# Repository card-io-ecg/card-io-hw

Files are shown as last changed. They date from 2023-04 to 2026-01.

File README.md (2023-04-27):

Card/IO hardware
================

Card/IO is an open source, single lead ECG in a business card-like format.

The project contains two PCB designs, created using KiCAD 7:
 
 - main_board: main/carrier board, which is a 4 layer PCB containing the MCU, display, battery and related circuitry
 - frontend: the ECG frontend, ADC, and touch detection/wakeup generator, implemented as a solder-on daughter board

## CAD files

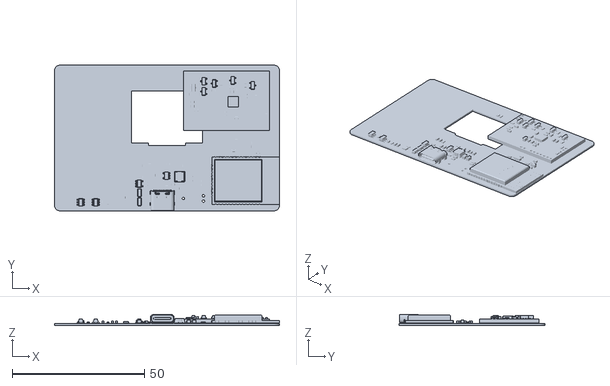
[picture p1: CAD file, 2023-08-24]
enclosure/main_board.stl
85.0 x 55.0 x 4.26

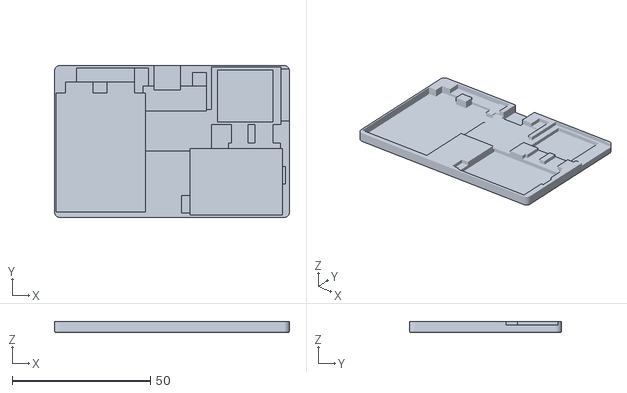
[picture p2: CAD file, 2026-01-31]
enclosure/enclosure.stl
85.0 x 55.0 x 4.00

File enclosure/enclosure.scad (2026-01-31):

include <rounded_rect.scad>

$fn = 50;

/* Set to false if you want to render the box */
design = false; // draw the box or the PCB and the part cutouts
drawBoard = false; // draw the board on top of the box in !design
fullHeight = true; // display flat overlays or the full height cutouts

flatCutout = design && !fullHeight;

boardThickness = 0.8;
nominalBoardWidth = 85;
nominalBoardHeight = 55;

partMaskHeight =       flatCutout ? 0.1 : 1.5;
highPartMaskHeight =   flatCutout ? 0.1 : 2;
frontendMaskHeight =   flatCutout ? 0.1 : 3;
espMaskHeight =        flatCutout ? 0.1 : 3;
espPcbMaskHeight =     flatCutout ? 0.1 : 1.2;
batteryMaskHeight =    flatCutout ? 0.1 : 3;
usbHeight =            flatCutout ? 1   : 3.4;

wallThickness = 0.6;
wallHeight = 3.4;
edgeRounding = 1;
cornerRadius = 1.4;

boxWidth = nominalBoardWidth;
boxHeight = nominalBoardHeight;

module boardAndParts()
{
    /* Display */
    color("blue")
    translate([29, 24.6, -partMaskHeight])
    cube([27.8, 20, partMaskHeight]);
    translate([29, 16, 0])
    cube([27.8, 15, partMaskHeight]);
    //*/

    /* USB port body */
    color("purple")
    translate([36, -0.2, 0])
    cube([9.5, 9, usbHeight]);
    //*/

    /* Battery */
    translate([4, 6, 0])
    cube([10, 7, batteryMaskHeight]);
    translate([19, 6, 0])
    cube([10, 7, batteryMaskHeight]);
    translate([0.6, 10, 0])
    cube([32.4, 43, batteryMaskHeight]);
    //*/

    /* Battery protection */
    translate([8, 1, 0])
    cube([21, 5, highPartMaskHeight]);
    //*/

    /* Battery charger */
    translate([29, 1, 0])
    cube([5, 12, partMaskHeight]);
    //*/

    /* PSU */
    color("purple")
    translate([32, 7.5, 0])
    cube([23, 9, highPartMaskHeight]);
    //*/

    /* ===== MCU ===== */
    translate([60, 1.2, 0])
    cube([27, 18.8, espPcbMaskHeight]);
    translate([59, 1.6, 0])
    cube([20, 18.8, espMaskHeight]);
    /* MCU pads */
    color("purple")
    translate([56.8, 0.6, 0])
    cube([25.2, 20.8, partMaskHeight]);
    //*/
    /* MCU others */
    // XTAL32K
    translate([64, 21, 0])
    cube([6, 7, partMaskHeight]);
    // reset resistor / bypass caps
    translate([72.5, 21, 0])
    cube([6.5, 8, partMaskHeight]);
    // I2C resistors
    color("purple")
    translate([50, 2.5, 0])
    cube([5, 5, partMaskHeight]);
    //*/

    /* ===== Analog frontend ===== */
    translate([49, 30, 0])
    cube([33.5, 24, frontendMaskHeight]);
    /* AFE pads */
    color("purple")
    translate([46, 47, 0])
    cube([3, 6.3, partMaskHeight]);
    color("purple")
    translate([80.5, 36.5, 0])
    cube([3, 6.3, partMaskHeight]);
    color("purple")
    translate([63, 28, 0])
    cube([18.7, 3, partMaskHeight]);
    //*/
}

if (!design)
{
    rotate([180, 0, 0])
    union() {
        translate([0, 0, - wallHeight - wallThickness])
        difference()
        {
            /* ===== Shell ===== */
            difference()
            {
                /* Box */
                translate([wallThickness, wallThickness, 0])
                minkowski()
                {
                    roundedRect([boxWidth-2*wallThickness, boxHeight-2*wallThickness, wallHeight], cornerRadius, false);
                    sphere(wallThickness);
                }
                    
                /* cut the bottom half */
                translate([-boxWidth, -boxHeight, -wallHeight])
                cube([3 * boxWidth, 3 * boxHeight, wallHeight]);
            }

            boardAndParts();
        }
        
        if (drawBoard) {
            color("green")
            translate([0, 0, -wallHeight -wallThickness - boardThickness])
            import("main_board.stl");
        }
    }
}
else
{
    color("green")
    translate([0, 0, -boardThickness])
    import("main_board.stl");
    boardAndParts();
}

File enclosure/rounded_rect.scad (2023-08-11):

module roundedRect(size, radius, center=false)
{
    x = size[0];
    y = size[1];
    z = size[2];
	
		dx = center ? x/2 : 0;
		dy = center ? y/2 : 0;
		dz = center ? z/2 : 0;
	
	translate([dx, dy, -dz])
    linear_extrude(height=z)
	hull()
    {
        // place 4 circles in the corners, with the given radius
        translate([radius, radius, 0])
        circle(r=radius);
		
        translate([x - radius, radius, 0])
        circle(r=radius);
		
        translate([radius, y - radius, 0])
        circle(r=radius);
		
        translate([x - radius, y - radius, 0])
        circle(r=radius);
    }
}

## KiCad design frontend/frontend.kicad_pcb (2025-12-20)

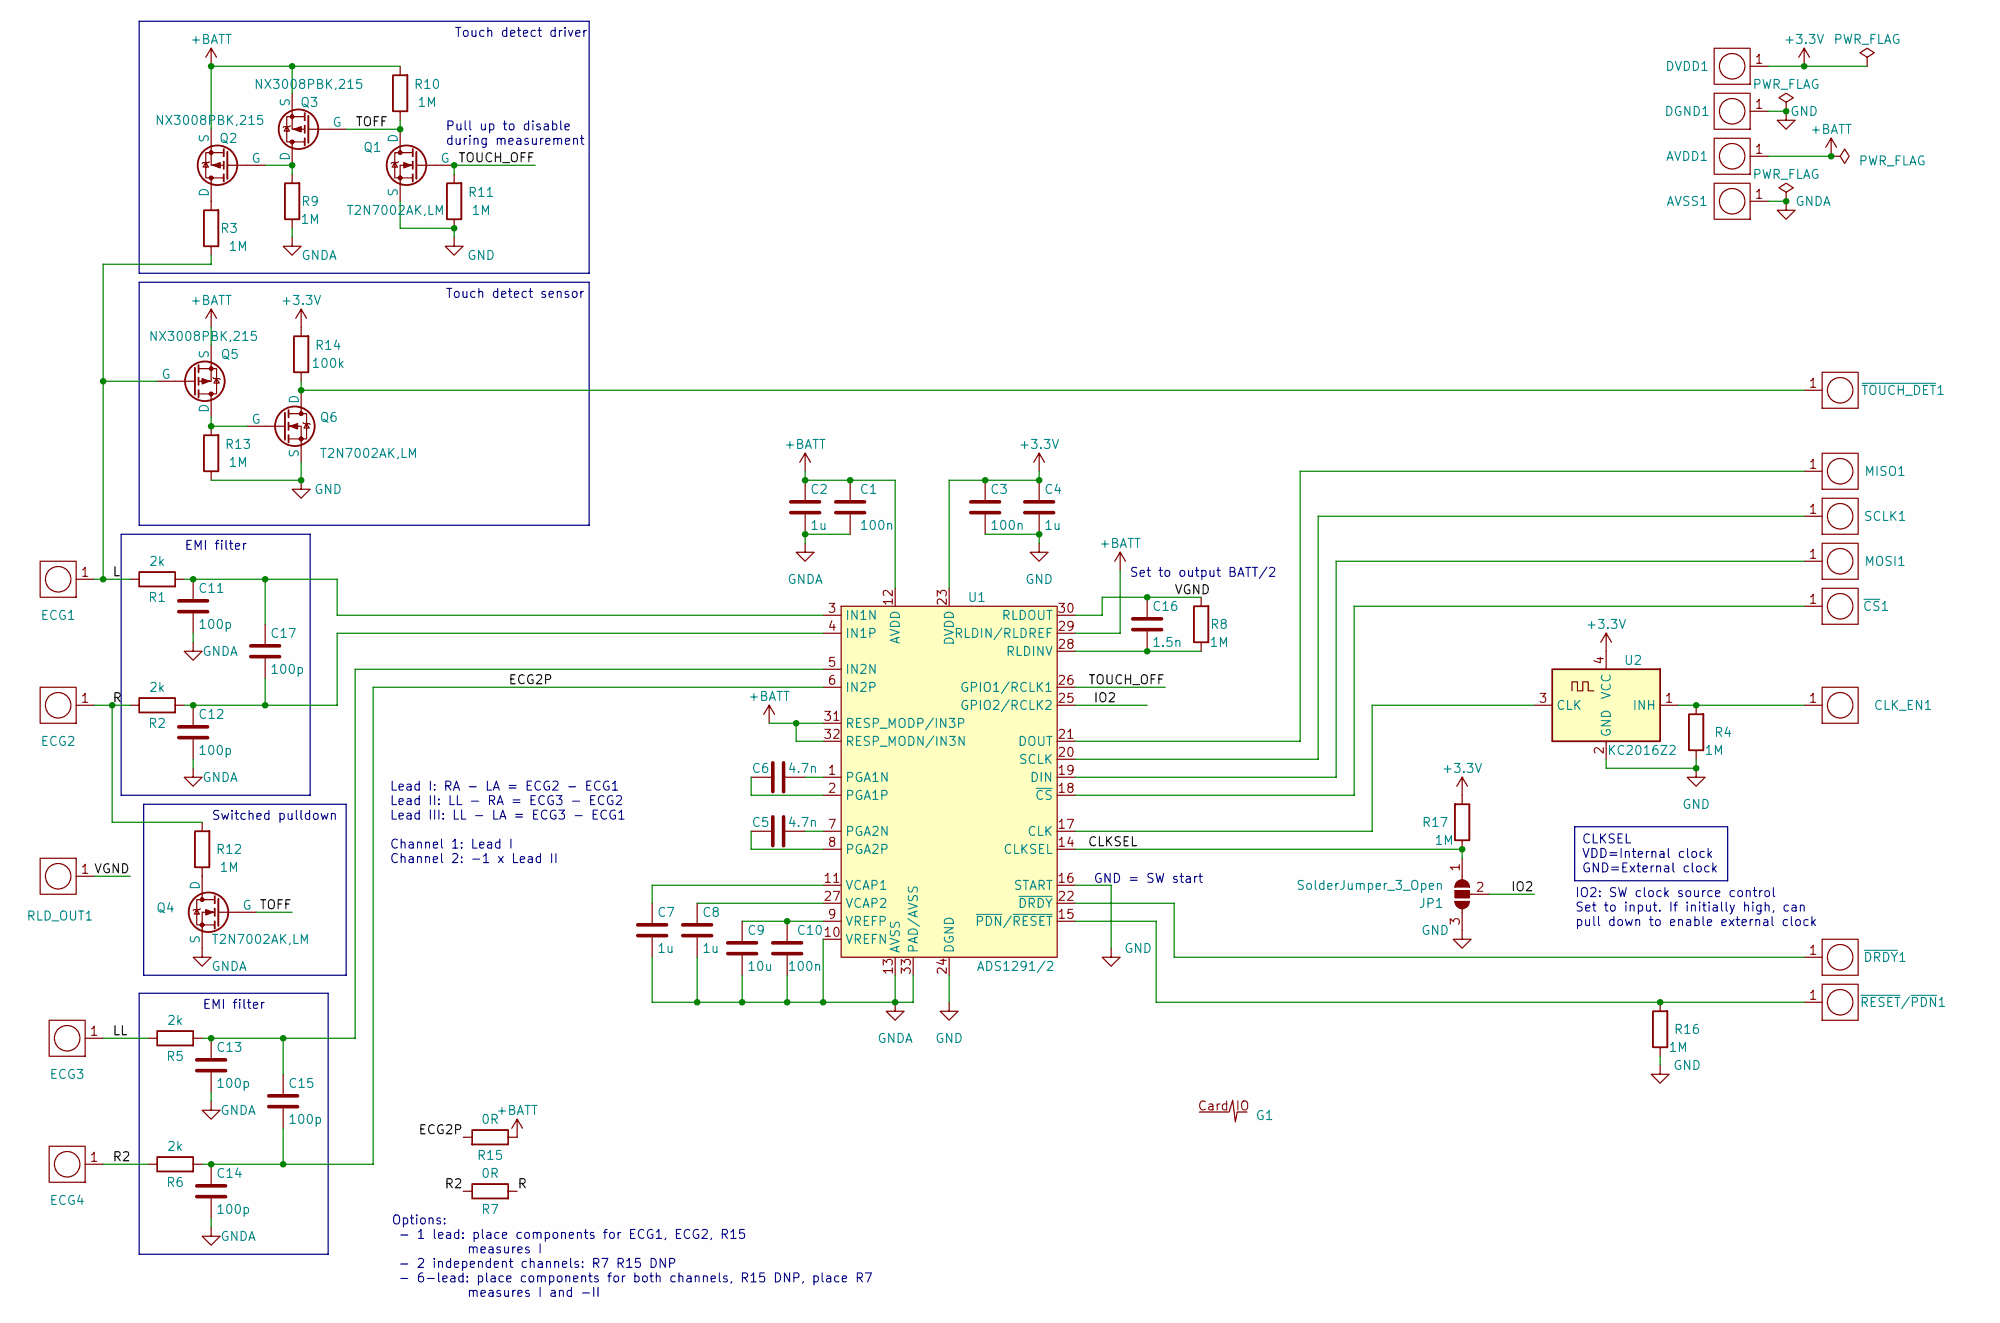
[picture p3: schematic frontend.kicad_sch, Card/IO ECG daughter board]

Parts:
AVDD1: PAD
AVSS1: PAD
C1, C3, C10: 100n; C_0603_1608Metric
C2, C4, C7, C8: 1u; C_0603_1608Metric
C5, C6: 4.7n; C_0603_1608Metric
C9: 10u; C_0805_2012Metric
C11, C12, C13, C14, C15, C17: 100p; C_0603_1608Metric
C16: 1.5n; C_0603_1608Metric
CLK_EN1: PAD
DGND1: PAD
DVDD1: PAD
ECG1, ECG2, ECG3, ECG4: PAD
G1: logo
JP1: SolderJumper_3_Open; SolderJumper-3_P1.3mm_Open_RoundedPad1.0x1.5mm
MISO1: PAD
MOSI1: PAD
Q1, Q4, Q6: T2N7002AK,LM; SOT-23
Q2, Q3, Q5: NX3008PBK,215; SOT-23
R1, R2, R5, R6: 2k; R_0603_1608Metric
R3, R4, R8, R9, R10, R11, R12, R13, R16, R17: 1M; R_0603_1608Metric
R7, R15: 0R; R_0603_1608Metric
R14: 100k; R_0603_1608Metric
RLD_OUT1: PAD
SCLK1: PAD
U1: ADS1291/2; ADS1291-2
U2: KC2016Z2; KC2016Z
~{CS}1: PAD
~{DRDY}1: PAD
~{RESET}/~{PDN}1: PAD
~{TOUCH_DET}1: PAD

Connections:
+3.3V: C3.1, C4.1, DVDD1.1, R14.2, R17.2, U1.23 (DVDD), U2.4 (VCC)
+BATT: AVDD1.1, C1.1, C2.1, Q2.2 (S), Q3.2 (S), Q5.2 (S), R10.2, R15.1, U1.12 (AVDD), U1.29 (RLDIN/RLDREF), U1.31 (RESP_MODP/IN3P), U1.32 (RESP_MODN/IN3N)
/CLKSEL: JP1.1 (A), R17.1, U1.14 (CLKSEL)
/ECG2P: C14.1, C15.2, R6.2, R15.2, U1.6 (IN2P)
/IO2: JP1.2 (C), U1.25 (GPIO2/RCLK2)
/L: ECG1.1, Q5.1 (G), R1.1, R3.1
/LL: ECG3.1, R5.1
/R: ECG2.1, R2.1, R7.2, R12.2
/R2: ECG4.1, R6.1, R7.1
/TOFF: Q1.3 (D), Q3.1 (G), Q4.1 (G), R10.1
/TOUCH_OFF: Q1.1 (G), R11.2, U1.26 (GPIO1/RCLK1)
/VGND: C16.1, R8.2, RLD_OUT1.1, U1.30 (RLDOUT)
GND: C3.2, C4.2, DGND1.1, JP1.3 (B), Q1.2 (S), Q6.2 (S), R4.1, R11.1, R13.1, R16.1, U1.16 (START), U1.24 (DGND), U2.2 (GND)
GNDA: AVSS1.1, C1.2, C2.2, C7.2, C8.2, C9.2, C10.2, C11.2, C12.2, C13.2, C14.2, Q4.2 (S), R9.1, U1.10 (VREFN), U1.13 (AVSS), U1.33 (PAD/AVSS)
unnamed: Q2.3 (D), R3.2
unnamed: Q2.1 (G), Q3.3 (D), R9.2
unnamed: Q4.3 (D), R12.1
unnamed: Q5.3 (D), Q6.1 (G), R13.2
unnamed: Q6.3 (D), R14.1, ~{TOUCH_DET}1.1
unnamed: U1.17 (CLK), U2.3 (CLK)
unnamed: MOSI1.1, U1.19 (DIN)
unnamed: MISO1.1, U1.21 (DOUT)
unnamed: C11.1, C17.1, R1.2, U1.3 (IN1N)
unnamed: C12.1, C17.2, R2.2, U1.4 (IN1P)
unnamed: C13.1, C15.1, R5.2, U1.5 (IN2N)
unnamed: C6.1, U1.1 (PGA1N)
unnamed: C6.2, U1.2 (PGA1P)
unnamed: C5.1, U1.7 (PGA2N)
unnamed: C5.2, U1.8 (PGA2P)
unnamed: C16.2, R8.1, U1.28 (RLDINV)
unnamed: SCLK1.1, U1.20 (SCLK)
unnamed: C7.1, U1.11 (VCAP1)
unnamed: C8.1, U1.27 (VCAP2)
unnamed: C9.1, C10.1, U1.9 (VREFP)
unnamed: U1.18 (~CS), ~{CS}1.1
unnamed: U1.22 (~DRDY), ~{DRDY}1.1
unnamed: R16.2, U1.15 (~PDN/~RESET), ~{RESET}/~{PDN}1.1
unnamed: CLK_EN1.1, R4.2, U2.1 (INH)

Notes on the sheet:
Touch detect driver
Touch detect sensor
EMI filter
Set to output BATT/2
GND = SW start
Options: - 1 lead: place components for ECG1, ECG2, R15 measures I - 2 independent channels: R7 R15 DNP - 6-lead: place components for both channels, R15 DNP, place R7 measures I and -II
Lead I: RA - LA = ECG2 - ECG1 Lead II: LL - RA = ECG3 - ECG2 Lead III: LL - LA = ECG3 - ECG1 Channel 1: Lead I Channel 2: -1 x Lead II
Switched pulldown
Pull up to disable during measurement
IO2: SW clock source control Set to input. If initially high, can pull down to enable external clock
CLKSEL VDD=Internal clock GND=External clock

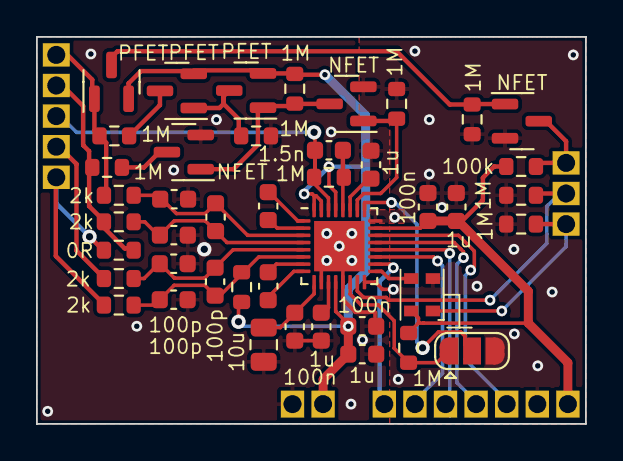
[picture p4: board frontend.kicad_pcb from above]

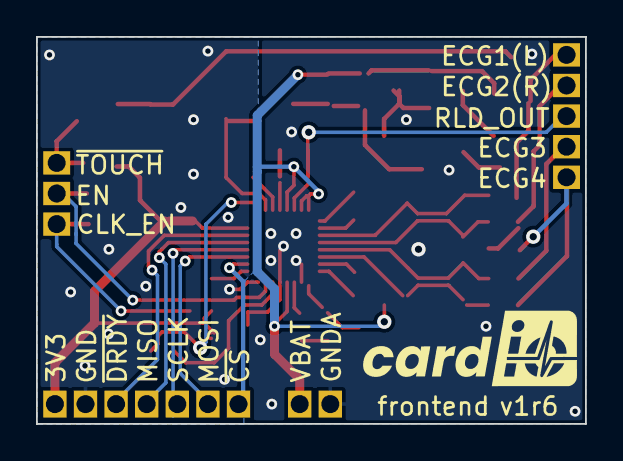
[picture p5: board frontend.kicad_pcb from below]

Board: 2 copper layers, 30.5 x 21.5 mm, 57 parts (2 on the bottom side), 36 nets.

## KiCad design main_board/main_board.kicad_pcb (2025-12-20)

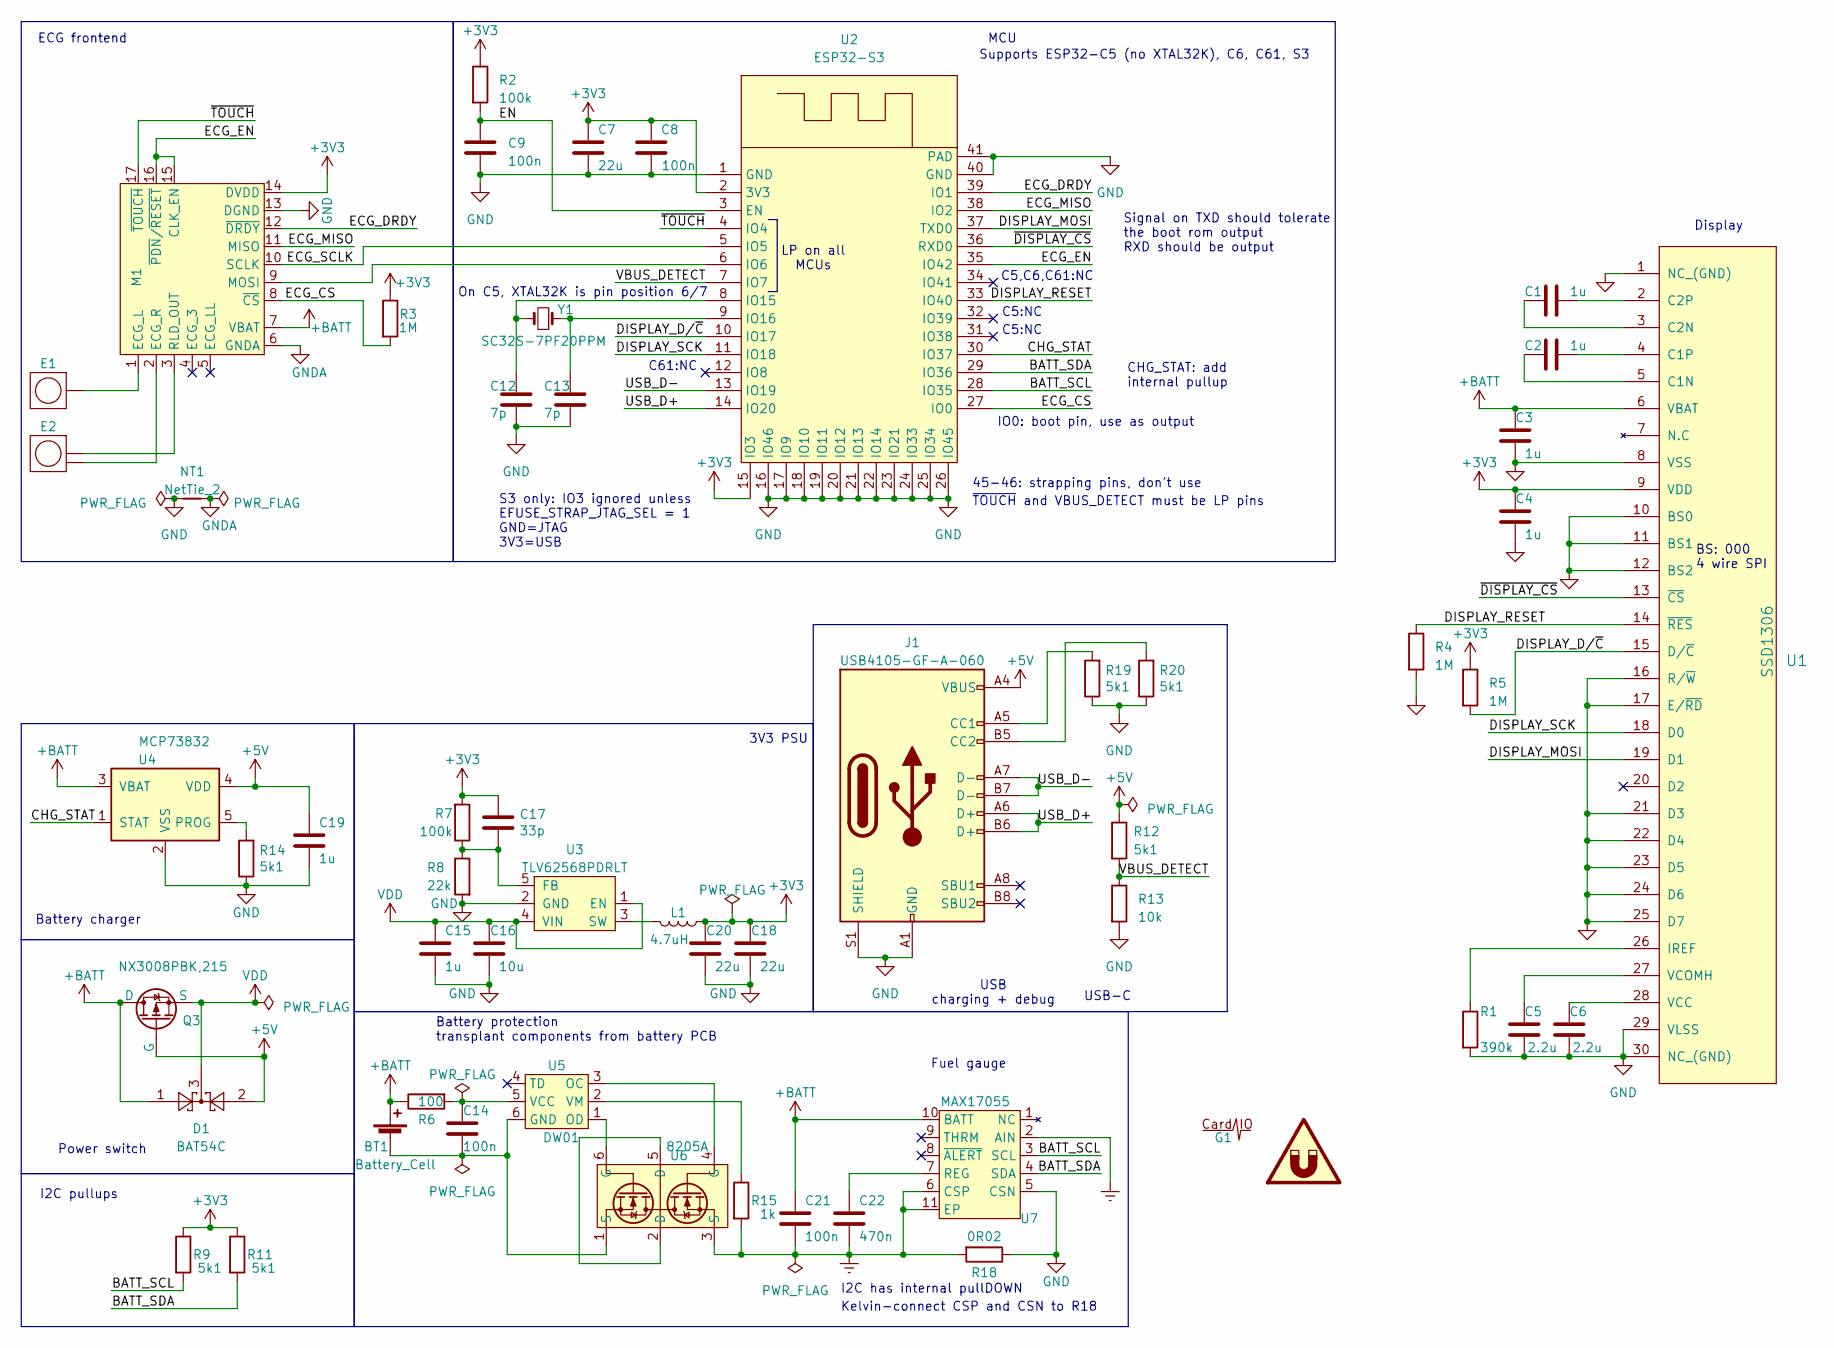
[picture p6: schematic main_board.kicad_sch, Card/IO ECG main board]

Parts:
BT1: Battery_Cell; Battery_transplant
C1, C2, C3, C4: 1u; C_0603_1608Metric
C5, C6: 2.2u; C_0603_1608Metric
C7: 22u; C_0805_2012Metric
C8, C9, C14: 100n; C_0603_1608Metric
C12, C13: 7p; C_0603_1608Metric
C15, C19: 1u; C_0603_1608Metric; MPN CL10A105KP8NNWC
C16: 10u; C_0603_1608Metric; MPN JMK107ABJ106MA-T
C17: 33p; C_0603_1608Metric; MPN C0603C330M5HACTU
C18, C20: 22u; C_0805_2012Metric; MPN 0805X226M6R3CT
C21: 100n; C_0603_1608Metric; MPN CL10A105KP8NNWC
C22: 470n; C_0603_1608Metric; MPN CL10A105KP8NNWC
D1: BAT54C; SOT-23
E1: Electrode
E2: SplitElectrode
G1: logo
J1: USB4105-GF-A-060; USB_C_Receptacle_GCT_USB4105-xx-A_16P_TopMnt_Horizontal
L1: 4.7uH; TYA40124R7M-10; MPN TYA40124R7M-10
M1: ECG-module_1lead
NT1: NetTie_2; NetTie-2_SMD_Pad2.0mm
Q3: NX3008PBK,215; SOT-23
QR1: SYM_Magnet_Large; website-qr
R1: 390k; R_0603_1608Metric
R2: 100k; R_0603_1608Metric
R3, R4, R5: 1M; R_0603_1608Metric
R6: 100; R_0603_1608Metric; MPN RC0603FR-072KL
R7: 100k; R_0603_1608Metric; MPN RC0603JR-07100KL
R8: 22k; R_0603_1608Metric; MPN RC0603FR-0722KL
R9, R11, R12: 5k1; R_0603_1608Metric
R13: 10k; R_0603_1608Metric
R14, R19, R20: 5k1; R_0603_1608Metric; MPN RC0603FR-072KL
R15: 1k; R_0603_1608Metric
R18: 0R02; R_0603_1608Metric
U1: SSD1306
U2: ESP32-S3; ESP32-WROOM-1-COMBO
U3: TLV62568PDRLT; SOT-23-5
U4: MCP73832; SOT-23-5
U5: DW01; SOT-23-6
U6: 8205A; SOT-23-6
U7: MAX17055
Y1: SC32S-7PF20PPM; Crystal_SMD_MicroCrystal_CC7V-T1A-2Pin_3.2x1.5mm

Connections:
+3V3: C4.2, C7.1, C8.1, C17.1, C18.1, C20.1, L1.1, M1.14 (DVDD), R2.1, R3.1, R5.1, R7.2, R9.1, R11.1, U1.9 (VDD), U2.2 (3V3), U2.15 (IO3)
+5V: C19.1, D1.2, J1.A4 (VBUS), J1.A9 (VBUS), J1.B4 (VBUS), J1.B9 (VBUS), Q3.1 (G), R12.1, U4.4 (VDD)
+BATT: BT1.1 (+), C3.2, C21.1, D1.1, M1.7 (VBAT), Q3.3 (D), R6.1, U1.6 (VBAT), U4.3 (VBAT), U7.10 (BATT)
/BATT_SCL: R9.2, U2.28 (IO35), U7.3 (SCL)
/BATT_SDA: R11.2, U2.29 (IO36), U7.4 (SDA)
/CHG_STAT: U2.30 (IO37), U4.1 (STAT)
/DISPLAY_D/~C: R5.2, U1.15 (D/~C), U2.10 (IO17)
/DISPLAY_MOSI: U1.19 (D1), U2.37 (TXD0)
/DISPLAY_RESET: R4.1, U1.14 (~RES), U2.33 (IO40)
/DISPLAY_SCK: U1.18 (D0), U2.11 (IO18)
/ECG_CS: M1.8 (~CS), R3.2, U2.27 (IO0)
/ECG_DRDY: M1.12 (~DRDY), U2.39 (IO1)
/ECG_EN: M1.15 (CLK_EN), M1.16 (~PDN/~RESET), U2.35 (IO42)
/ECG_MISO: M1.11 (MISO), U2.38 (IO2)
/ECG_SCLK: M1.10 (SCLK), U2.5 (IO5)
/EN: C9.1, R2.2, U2.3 (EN)
/USB_D+: J1.A6 (D+), J1.B6 (D+), U2.14 (IO20)
/USB_D-: J1.A7 (D-), J1.B7 (D-), U2.13 (IO19)
/VBUS_DETECT: R12.2, R13.1, U2.7 (IO7)
/~DISPLAY_CS: U1.13 (~CS), U2.36 (RXD0)
/~TOUCH: M1.17 (~TOUCH), U2.4 (IO4)
Earth: C21.2, C22.2, R15.2, R18.2, U6.3 (S), U7.2 (AIN), U7.6 (CSP), U7.11 (EP)
GND: C3.1, C4.1, C5.1, C6.1, C7.2, C8.2, C9.2, C12.1, C13.1, C15.2, C16.2, C18.2, C19.2, C20.2, J1.A1 (GND), J1.A12 (GND), J1.B1 (GND), J1.B12 (GND), J1.S1 (SHIELD), M1.13 (DGND), NT1.1, R1.2, R4.2, R8.2, R13.2, R14.1, R18.1, R19.1, R20.1, U1.1 (NC_(GND)), U1.8 (VSS), U1.10 (BS0), U1.11 (BS1), U1.12 (BS2), U1.16 (R/~W), U1.17 (E/~RD), U1.21 (D3), U1.22 (D4), U1.23 (D5), U1.24 (D6), U1.25 (D7), U1.29 (VLSS), U1.30 (NC_(GND)), U2.1 (GND), U2.16 (IO46), U2.17 (IO9), U2.18 (IO10), U2.19 (IO11), U2.20 (IO12), U2.21 (IO13), U2.22 (IO14), U2.23 (IO21), U2.24 (IO33), U2.25 (IO34), U2.26 (IO45), U2.40 (GND), U2.41 (PAD), U3.2 (GND), U4.2 (VSS), U7.5 (CSN)
GNDA: M1.6 (GNDA), NT1.2
unnamed: BT1.2 (-), C14.2, U5.6 (GND), U6.1 (S)
unnamed: J1.A5 (CC1), R19.2
unnamed: J1.B5 (CC2), R20.2
unnamed: E1.1, M1.1 (ECG_L)
unnamed: E2.2, M1.2 (ECG_R)
unnamed: M1.9 (MOSI), U2.6 (IO6)
unnamed: E2.1, M1.3 (RLD_OUT)
unnamed: C2.1, U1.5 (C1N)
unnamed: C2.2, U1.4 (C1P)
unnamed: C1.1, U1.3 (C2N)
unnamed: C1.2, U1.2 (C2P)
unnamed: R1.1, U1.26 (IREF)
unnamed: C6.2, U1.28 (VCC)
unnamed: C5.2, U1.27 (VCOMH)
unnamed: C12.2, U2.8 (IO15), Y1.2
unnamed: C13.2, U2.9 (IO16), Y1.1
unnamed: C17.2, R7.1, R8.1, U3.5 (FB)
unnamed: L1.2, U3.3 (SW)
unnamed: R14.2, U4.5 (PROG)
unnamed: U5.3 (OC), U6.4 (G)
unnamed: U5.1 (OD), U6.6 (G)
unnamed: C14.1, R6.2, U5.5 (VCC)
unnamed: R15.1, U5.2 (VM)
unnamed: U6.2 (D), U6.5 (D)
unnamed: C22.1, U7.7 (REG)
VDD: C15.1, C16.1, D1.3, Q3.2 (S), U3.1 (EN), U3.4 (VIN)

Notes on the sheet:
IO0: boot pin, use as output
Supports ESP32-C5 (no XTAL32K), C6, C61, S3
Signal on TXD should tolerate the boot rom output RXD should be output
USB-C
On C5, XTAL32K is pin position 6/7
LP on all MCUs
ECG frontend
C5:NC
Kelvin-connect CSP and CSN to R18
C5,C6,C61:NC
MCU
Battery charger
CHG_STAT: add internal pullup
Fuel gauge
~{TOUCH} and VBUS_DETECT must be LP pins
3V3 PSU
BS: 000 4 wire SPI
45-46: strapping pins, don't use
I2C has internal pullDOWN
Battery protection transplant components from battery PCB
I2C pullups
Display
S3 only: IO3 ignored unless EFUSE_STRAP_JTAG_SEL = 1 GND=JTAG 3V3=USB
Power switch
C61:NC
USB charging + debug

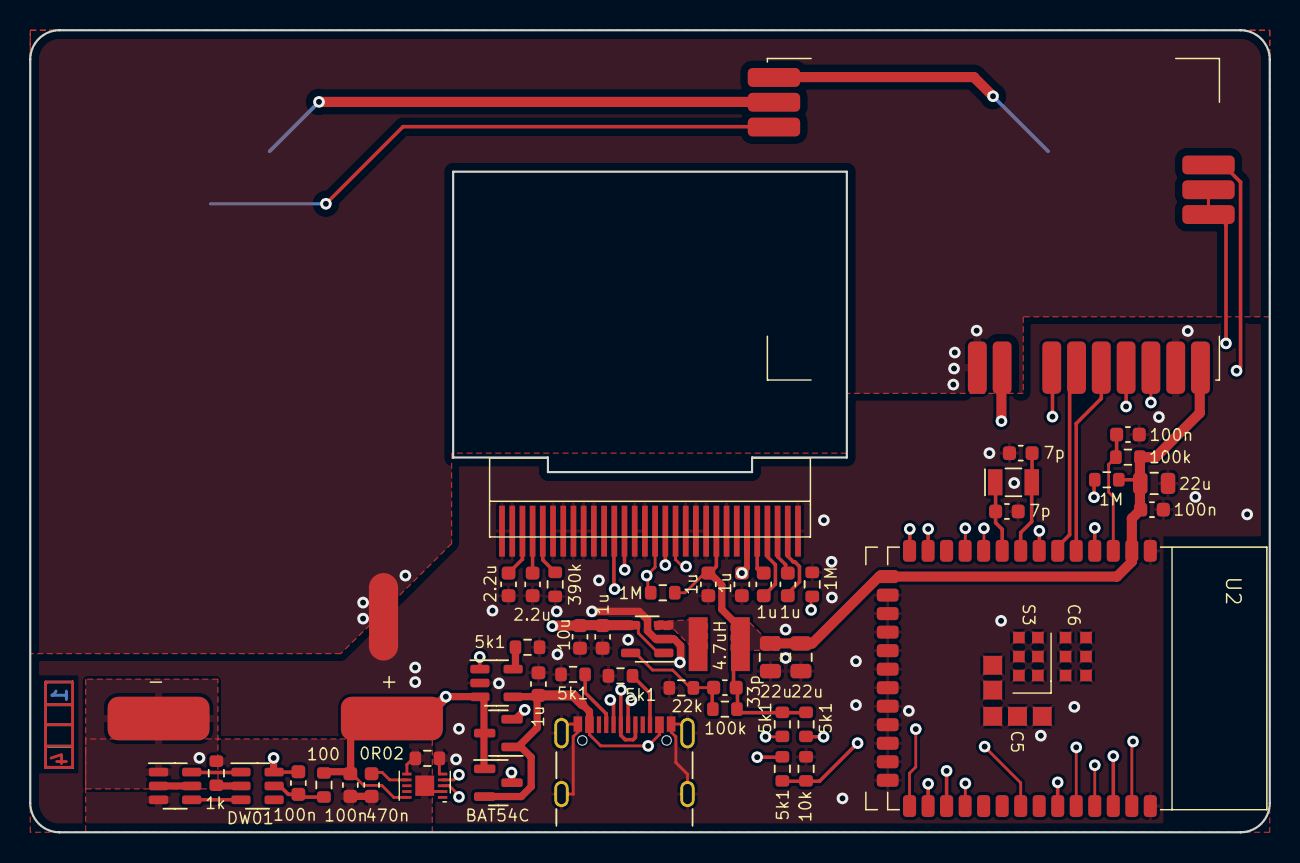
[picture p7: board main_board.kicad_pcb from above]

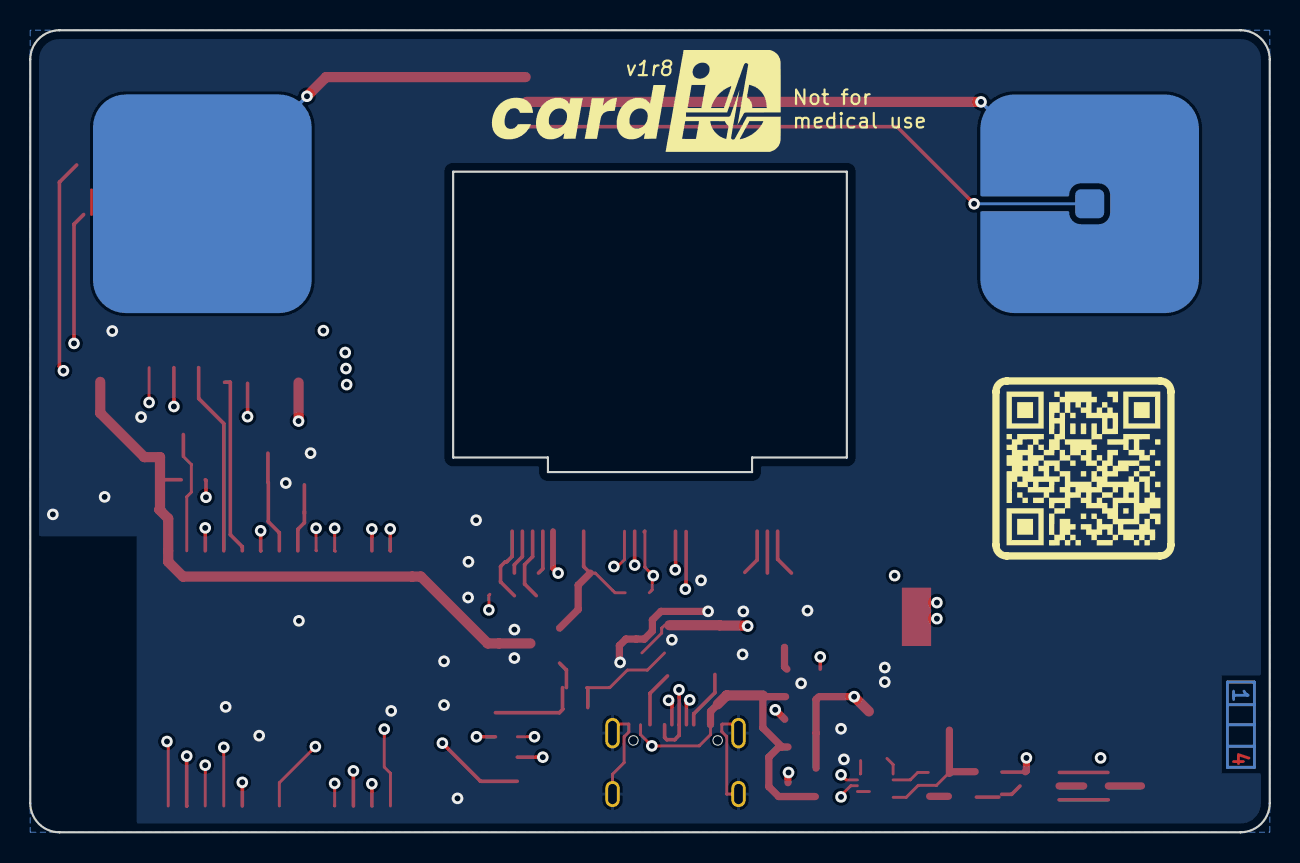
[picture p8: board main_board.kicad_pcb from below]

Board: 4 copper layers, 85.0 x 55.0 mm, 56 parts (4 on the bottom side), 50 nets.

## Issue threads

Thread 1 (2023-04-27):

Set up KiBot to generate fabrication files, interactive BOM for release

bugadani, 2023-04-27:

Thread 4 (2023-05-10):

Pulling up IO0 is unnecessary and prevents initial JTAG connection

bugadani, 2023-05-10:
Resolution: remove the connection to 3v3. First flashing will require two tweezers to put the board into download mode, this needs to be documented.

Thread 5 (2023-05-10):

Scope signal of touch release detection is slow/noisy

bugadani, 2023-05-10:
It looks like the detector could use a Schmitt-trigger, but it might just be 50Hz noise.

Resolution:
 - software
 - 100k for R3 and 50k for R12 provide good input speeds

Closed 2023-05-19.

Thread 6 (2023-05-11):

Add component values to silk screen

bugadani, 2023-05-11:

bugadani, 2023-06-04:
FE: [970efb5](https://github.com/card-io-ecg/card-io-hw/commit/970efb5c48490d61a5e57e3b44993b231a3b540a)

bugadani, 2023-06-04:
Main board: [55d8279](https://github.com/card-io-ecg/card-io-hw/commit/55d82799f9d6317fb49e46dbdec8aeac707c97ef)

Closed 2023-06-04.

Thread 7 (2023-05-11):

Move battery and surrounding components to give some space to an enclosure wall

bugadani, 2023-05-11:

Closed 2023-05-11.

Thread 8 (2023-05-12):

No way to place ADS into power down mode

bugadani, 2023-05-12:
> If the device is powered down it is reset first and then if 2^10 clock elapses it is powered down.

This indicates that the external clock should be active for a short time after taking the reset line low.

bugadani, 2023-05-16:
Chip select can be repurposed as the signal that keeps the clock running.

Closed 2023-05-19.

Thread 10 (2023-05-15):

Move components away from board edge

bugadani, 2023-05-15:
- frontend: 8c6aa9c
 - ESP

Closed 2023-06-03.

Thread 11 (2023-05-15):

RLD buffer is active after measure state is exited

bugadani, 2023-05-15:
Correction: buffer is powered down, but the resistors provide a current path via the touch detection circuit, which isn't ideal.

bugadani, 2023-05-16:
Can lead-off detection with flipped current direction help here?

bugadani, 2023-05-17:
Removing R7 seems to be a decent workaround. Removing R6, too, introduces high-frequency noise into the measurement

bugadani, 2023-05-18:
Resolution: Remove R6 and R7.

Closed 2023-05-19.

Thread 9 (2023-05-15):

Consider generating ADS clock by the MCU

bugadani, 2023-05-15:
- we have the space for the additional pad
 - reduce cost
 - would allow entering power down mode without tricky circuitry to keep the clock running for a while - cc #8

bugadani, 2023-05-19:
Can't seem to generate an exact 2048kHz clock from 80MHz source.

Closed 2023-05-19.

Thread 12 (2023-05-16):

ADC "switch" lets current flow through the MCU while disabled

bugadani, 2023-05-16:

bugadani, 2023-05-18:
Resolution: replace low-side NFET with high-side PFET switched by low-side NFET.

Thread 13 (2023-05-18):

Device should be reset while charging if the battery is deeply discharged

bugadani, 2023-05-18:

bugadani, 2023-05-25:
Closing in favour of #23

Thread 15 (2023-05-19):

Transplant battery protection components to PCB

bugadani, 2023-05-19:
This will allow soldering the battery to the PCB directly instead short wires.

bugadani, 2023-05-25:
Battery terminals: 8b24f88

Closed 2023-05-26.

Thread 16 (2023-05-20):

Move JTAG to the front side

bugadani, 2023-05-20:
Without the 4 holes for the clips, the connector could go below the MCU.

Closed 2023-05-25.

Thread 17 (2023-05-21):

The display cutout can be moved further down

bugadani, 2023-05-21:
The cutout can move as far as the connector is, the flex cable can fold just fine.

Closed 2023-05-22.

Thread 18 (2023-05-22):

Add RLD output to frontend pads

bugadani, 2023-05-22:
RLD should not be connected to the leads directly, as the resistors interfere with touch detection. However, RLD is a good way to keep the differential signal in range in case the 22nA lead-off current is not enough. Outputting the voltage allows modifying the main board with split electrodes that can route the voltage to either or both fingers.

Closed 2023-05-22.

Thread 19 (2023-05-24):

Move ADC inputs to ADC1

bugadani, 2023-05-24:

Closed 2023-05-25.

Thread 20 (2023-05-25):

Consider using an LDO instead of the buck converter

bugadani, 2023-05-25:

Closed 2023-08-24.

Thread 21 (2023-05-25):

Add split electrodes for RLD output

bugadani, 2023-05-25:

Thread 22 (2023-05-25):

Consider opamps for ADC inputs

bugadani, 2023-05-25:

bugadani, 2023-06-02:
https://github.com/card-io-rs/card-io-hw/issues/25

Closed 2023-06-02.

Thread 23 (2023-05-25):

Supply MCU through a diode while charging

bugadani, 2023-05-25:

bugadani, 2023-06-04:
This isn't strictly necessary now that the MCU sleeps while charging, but it might still be a good idea to protect the battery during debugging and wifi AP operation while charging.

Closed 2023-06-05.

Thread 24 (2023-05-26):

Move VBUS detect to an RTC pin

bugadani, 2023-05-26:

Closed 2023-06-01.

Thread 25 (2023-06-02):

Add a fuel gauge

bugadani, 2023-06-02:
Cheap: https://hu.mouser.com/ProductDetail/Richtek/RT9428WSC?qs=amGC7iS6iy8t6c1bqXqzXA%3D%3D
Cheapest non-BGA on Mouser: https://hu.mouser.com/ProductDetail/Analog-Devices-Maxim-Integrated/MAX17055ETB%2bT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

Closed 2023-06-03.

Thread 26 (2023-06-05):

Add new logo to PCBs

bugadani, 2023-06-05:

Closed 2023-06-05.

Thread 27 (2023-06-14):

Some parts have different footprints

bugadani, 2023-06-14:

Closed 2023-06-16.

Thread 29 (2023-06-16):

FW: swap VGND and right electrode pads

bugadani, 2023-06-16:

Closed 2023-06-16.

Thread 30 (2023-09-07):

Move charger status from GPIO46

bugadani, 2023-09-07:

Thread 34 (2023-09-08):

Mark non-BOM parts correctly

bugadani, 2023-09-08:

Closed 2023-09-09.

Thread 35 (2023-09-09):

Try symmetric resistor values in touch detection

bugadani, 2023-09-09:

bugadani, 2023-09-11:
c59aade

Closed 2023-09-11.

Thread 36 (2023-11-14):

Charger can't wake up ESP32-C6

bugadani, 2023-11-14:

Closed 2023-11-14.

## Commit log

2023-04-27 Correct battery charger
    [frontend.kicad_pcb, main_board.kicad_pcb, main_board.kicad_sch]
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2023-05-11 Fix #4: Remove IO0 pullup
    [main_board.kicad_pcb, main_board.kicad_sch]
2023-05-11 Enlarge keepout zone
    [main_board.kicad_pcb]
2023-05-11 Fix #7: move battery
    [main_board.kicad_pcb, main_board.kicad_sch]
2023-05-11 Allow reading back CLKSEL
    [frontend.kicad_pcb, frontend.kicad_sch]
2023-05-19 Fix #11: remove filters
    [frontend.kicad_sch]
2023-05-19 Fix #5: tune touch detector resistors
    [frontend.kicad_sch]
2023-05-19 Fix #8: add input to disable oscillator
    [frontend.kicad_sch]
2023-05-19 Update frontend layout
    [frontend.kicad_pcb, frontend.kicad_sch]
2023-05-22 Fix #17: Move display cutout
    [main_board.kicad_pcb]
2023-05-22 Fix #12: add PFET
    [main_board.kicad_pcb, main_board.kicad_sch]
2023-05-22 Fix #18: add RLD output, fix main board revision
    [frontend.kicad_pcb, frontend.kicad_sch, main_board.kicad_pcb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]
2023-05-23 Add clken to symbol, connect to MCU
    [main_board.kicad_sch]
2023-05-23 Add changes to layout
    [main_board.kicad_pcb]
2023-05-25 Fix #19: shuffle pin assignment
    [main_board.kicad_pcb, main_board.kicad_sch]
2023-05-25 Fix #16: move JTAG to front side
    [main_board.kicad_pcb, main_board.kicad_sch]
2023-05-25 Tweak routing a bit
    [main_board.kicad_pcb]
2023-05-25 Place battery terminals directly onto PCB
    [main_board.kicad_pcb, main_board.kicad_sch]
2023-05-26 Close #15: add battery protection components
    [main_board.kicad_pcb, main_board.kicad_sch]
2023-05-26 Add more output capacitance to DC/DC
    [main_board.kicad_pcb, main_board.kicad_sch]
2023-05-26 Move electrodes a bit
    [main_board.kicad_pcb]
2023-05-26 Move frontend away from the edge
    [main_board.kicad_pcb]
2023-05-27 Tweak frontend routing
    [frontend.kicad_pcb, frontend.kicad_sch]
2023-06-01 Fix #24: move VBUS detect to IO17
    [main_board.kicad_pcb, main_board.kicad_sch]
2023-06-01 Add logo
    [main_board.kicad_pcb, main_board.kicad_sch]
2023-06-01 Fix #21: Add split electrodes
    [main_board.kicad_pcb, main_board.kicad_sch]
2023-06-02 Fix #3: add QR code, exclude some parts from BOM
    [main_board.kicad_pcb, main_board.kicad_sch]
2023-06-03 Close #25: Add MAX17055
    [main_board.kicad_pcb, main_board.kicad_sch]
2023-06-03 Close #10: move ESP from board edge
    [main_board.kicad_pcb]
2023-06-04 Add logo to daughter board
    [frontend.kicad_pcb, frontend.kicad_sch]
2023-06-04 Add component values to daugther board
    [frontend.kicad_pcb, frontend.kicad_sch, main_board.kicad_sch]
2023-06-04 Update 3d model
    [main_board.kicad_pcb]
2023-06-04 Fix pad positions
    [main_board.kicad_pcb]
2023-06-04 Add component values to main board
    [main_board.kicad_pcb]
2023-06-04 Small tweaks
    [main_board.kicad_pcb]
2023-06-04 Tweak schematic a bit
    [main_board.kicad_pcb, main_board.kicad_sch]
2023-06-05 Close #23: supply MCU from charger
    [main_board.kicad_pcb, main_board.kicad_sch]
2023-06-05 Additional minor tweaks
    [main_board.kicad_pcb]
2023-06-05 Close #26: add new logo
    [frontend.kicad_pcb, main_board.kicad_pcb]
2023-06-05 Tweak frontend layout
    [frontend.kicad_pcb, frontend.kicad_sch]
2023-06-16 Fix #29: fix frontend PCB pad assignment
    [frontend.kicad_pcb, frontend.kicad_sch]
2023-06-16 Correct current sense value
    [main_board.kicad_pcb, main_board.kicad_sch]
2023-06-16 Correct charge current resistor value
    [main_board.kicad_pcb, main_board.kicad_sch]
2023-06-16 Remove unused metadata
    [main_board.kicad_pcb, main_board.kicad_sch]
2023-06-16 Close #27: unify footprints
    [main_board.kicad_pcb, main_board.kicad_sch]
2023-06-16 Update no-bom metadata
    [frontend.kicad_pcb, frontend.kicad_sch, main_board.kicad_pcb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]
2023-06-16 Fix label positions
    [frontend.kicad_pcb]
2023-07-19 Remove battery ADC parts, simplify and tweak routing, add locking holes to jtag
    [frontend.kicad_pcb, frontend.kicad_sch, main_board.kicad_pcb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]
2023-08-11 Add 3d models
    [main_board.kicad_pcb]
2023-08-11 Correct USB clipping into the board
    [main_board.kicad_pcb]
2023-08-11 Add enclosure design
    [enclosure.scad, enclosure.stl, main_board.stl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]
2023-08-13 Increase wall height
    [enclosure.scad, enclosure.stl]
2023-08-24 Tweak display cutout
    [main_board.kicad_pcb]
2023-08-24 Remove default link from jtag selector
    [main_board.kicad_pcb, main_board.kicad_sch]
2023-08-24 Remove JTAG silk screen
    [main_board.kicad_pcb]
2023-08-24 Replace USB with USB4105-GF-A-060
    [main_board.kicad_pcb, main_board.kicad_sch]
2023-08-24 Update enclosure
    [enclosure.scad, enclosure.stl, main_board.stl]
2023-08-24 Finalize v1r4
    [frontend.kicad_pcb, main_board.kicad_pcb, main_board.kicad_sch]
2023-09-07 Tweak enclosure
    [enclosure.scad, enclosure.stl]
2023-09-08 Close #31: tweak touch detection
    [frontend.kicad_pcb, frontend.kicad_sch]
2023-09-08 Close #32: Add missing silk screen
    [main_board.kicad_pcb, main_board.kicad_sch]
2023-09-08 Close #33: Clean up RLD
    [main_board.kicad_pcb, main_board.kicad_sch]
2023-09-08 Clean up
    [main_board.kicad_pcb, main_board.kicad_sch]
2023-09-08 Tweak split electrode
    [main_board.kicad_pcb]
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2023-09-11 Tweak touch detector circuit
    [frontend.kicad_pcb, frontend.kicad_sch, main_board.kicad_pcb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]
2023-09-18 Shrink frontend a bit
    [frontend.kicad_pcb, main_board.kicad_pcb]
2023-10-01 Fix rule violation, use a single plane on front side
    [main_board.kicad_pcb]
2023-10-07 Add second channel components
    [frontend.kicad_pcb, frontend.kicad_sch]
2023-11-03 Remove JTAG selector
    [main_board.kicad_pcb, main_board.kicad_sch]
2023-11-03 Replace battery alert input with ADC_EN
    [main_board.kicad_pcb, main_board.kicad_sch]
2023-11-03 Move frontend chip select to IO0
    [main_board.kicad_pcb, main_board.kicad_sch]
2023-11-03 Remove JTAG port
    [main_board.kicad_pcb, main_board.kicad_sch]
2023-11-03 Move display SPI to the right side of the module
    [main_board.kicad_pcb, main_board.kicad_sch]
2023-11-04 Tweak routing
    [main_board.kicad_pcb, main_board.kicad_sch]
2023-11-04 Tweak frontend
    [frontend.kicad_pcb, frontend.kicad_sch]
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2023-11-04 Final tweaks: switch ch2 electrodes
    [frontend.kicad_pcb, frontend.kicad_sch, main_board.kicad_pcb]
2023-11-05 Separate frontend reset from system enable
    [main_board.kicad_pcb, main_board.kicad_sch]
2023-11-14 Add a note about LP GPIO ranges
    [main_board.kicad_sch]
2023-11-14 Fix #36: swap VBUS_DETECT and DISPLAY_CS
    [main_board.kicad_pcb, main_board.kicad_sch]
2023-11-17 Keep fuel gauge comm lines pulled up
    [main_board.kicad_pcb, main_board.kicad_sch]
2023-11-20 Label the serial debug port, add strapping pullup
    [main_board.kicad_pcb, main_board.kicad_sch]
2023-11-20 Pull up D/C instead of CS
    [main_board.kicad_sch]
2023-11-22 Move VBUS_DETECT to a LP_IO pin
    [main_board.kicad_pcb, main_board.kicad_sch]
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2024-09-21 Remove useless serial port
    [main_board.kicad_pcb, main_board.kicad_sch]
2025-11-30 Update to kicad 9
    [frontend.kicad_pcb, frontend.kicad_sch, main_board.kicad_pcb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]
2025-11-30 Add C5/C61 options, mark as rev7
    [main_board.kicad_pcb, main_board.kicad_sch]
2025-12-17 Document C5 32k xtal difference
    [main_board.kicad_sch]
2025-12-20 r8: fix main board issues, update frontend clksel
    [frontend.kicad_pcb, frontend.kicad_sch, main_board.kicad_pcb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]
